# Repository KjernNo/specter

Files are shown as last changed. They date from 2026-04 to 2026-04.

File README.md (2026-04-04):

# SPECTER

SPECTER started as a little personal project, I just wanted to see what the 2.4GHz band looked like on a cheap NRF24L01 module and a Pico W. Then I added a menu. Then settings. Then OTA updates, a screensaver, a buzzer, battery monitoring and an easter egg. At some point I looked at it and thought "this is kind of a whole OS now" and figured, why not just open source it? So here we are.

It runs completely custom MicroPython firmware, no pre-built apps or libraries beyond the ssd1306 driver. The hardware is hand soldered on a 60x80mm perfboard and fits in your hand. Honestly if you are building one yourself I would go with a bigger board. 60x80mm is extremely compact and I had to use a slimmer 803160 1800mAh LiPo specifically because my usual 104050 cells are too wide and just would not fit. A bigger perfboard gives you way more headroom to work with and makes the whole build much less of a puzzle. The 60x80mm works but it is definitely not what you would call spacious haha.

Built by [Phillip Rødseth](https://kjern.no) / Kjern.no. Open source under CERN-OHL-W-2.0.

---

## What it actually does

There are 7 screens you can navigate between using the buttons. Here is what each one does and why it is useful:

**2.4G SPECTRUM**
This is the main attraction. The NRF24L01 scans every channel in the 2.4GHz band (2402-2480MHz) and draws a live bar graph across the full 128px width of the OLED. Each bar jumps up instantly when a signal is detected and falls off smoothly. There are peak markers that float above the bars and fall much slower so you can see where the action was even after it has moved on. WiFi shows up as wide solid blocks (it occupies about 20 channels at once), Bluetooth shows up as short spikes jumping around because it hops 1600 times per second. You can even hold it up against a running microwave and watch the higher frequencies light up as one big thick bar across the display, which is pretty fun :)

**WIFI SCANNER**
Uses the Pico W built in WiFi chip to scan for nearby networks. Lists them sorted by signal strength (strongest first) with SSID, dBm and channel. Scrollable with a scrollbar on the right edge.

**BT MONITOR**
Bluetooth Low Energy devices advertise themselves on three fixed channels (37, 38, 39) before they connect to anything. This screen watches all three simultaneously and shows live bar charts of activity per channel with peak markers. Good for seeing how many BLE devices are nearby.

**HOP COUNTER**
Counts how many times BLE devices switch between advertising channels per second, and plots that as a scrolling 20 second bar graph. More hops generally means more devices. Just a fun way to see the radio environment change as people walk in and out of range.

**SIGNAL METER**
A single big horizontal bar that shows signal strength on one specific channel. Use UP/DOWN to tune the channel up or down. Point the antenna at something and watch the bar react as you move closer or further away. Feels a bit like a metal detector but for radio signals. Also useful for finding which WiFi channel is least congested.

**STATS**
7 pages of real hardware stats. All of it is read from actual hardware, nothing is hardcoded or estimated. Battery voltage and percentage, CPU frequency, chip temperature from the internal sensor, RAM usage, flash usage, NRF status register, WiFi MAC address, unique chip ID, boot count and button press count this session. UP/DOWN scrolls between pages.

**SETTINGS**
Brightness, scan speed, bar decay rate, peak decay rate, battery update interval, buzzer on/off, WiFi setup and OTA firmware updates. WiFi setup has a full on-screen keyboard you can type into using the buttons. The error log viewer is also in here under "Error Log" which shows anything that crashed and got logged to flash.

---

## Hardware

You need these parts to build one:

| Part | Notes |
|---|---|
| Raspberry Pi Pico W | the brain, has built in WiFi which we use for the wifi scanner and OTA updates |
| NRF24L01+PA+LNA | the radio module, the PA+LNA version has an external antenna and is much more sensitive than the plain version |
| SSD1306 0.96" OLED | 128x64 pixels, I2C, the most common cheap OLED module around |
| 3.7V LiPo battery | single cell only, 1800-2500mAh works well |
| TP4056 charging module | handles charging safely, do not skip this |
| 5x tactile push switches | standard 6x6mm THT buttons |
| Passive piezo buzzer | needs PWM to make sound, the code drives it at 2500Hz which is a good middle ground for most passive buzzers |
| 10µF capacitor | not strictly necessary, but if your NRF acts weird when the radio activates (init failures, corrupted reads) it is usually just a voltage dip when the radio draws a burst of current. if you see this, solder a 10µF as close to the VCC and GND pins as you can and it will fix it :) |
| 2x 100kΩ resistors | voltage divider for the battery ADC sense |

For full wiring, see **[hardware/WIRING.md](hardware/WIRING.md)**. Read that before touching anything, especially the battery section. The schematic is in **[hardware/SCHEMATICS.pdf](hardware/SCHEMATICS.pdf)** if you want a technical view but WIRING.md is much easier to follow for actually building it.

> Seriously read the battery section in WIRING.md before connecting power. The voltage divider is not optional and wiring it wrong will permanently damage the ADC pin on your Pico.

---

## Installing

### The easy way, UF2 drag and drop

This is the recommended way for a first install. You do not need MicroPython installed already, the UF2 contains everything.

1. Hold **BOOTSEL** on the Pico W while plugging it into USB
2. It shows up on your computer as a USB drive called **RPI-RP2**
3. Go to [Releases](https://github.com/KjernNo/specter/releases) and download the latest **`specter-vX.X.X.uf2`**
4. Drag the UF2 file onto the RPI-RP2 drive
5. The drive disappears and the Pico reboots, SPECTER starts up

That's it. Took maybe 30 seconds.

### If SPECTER is already installed, OTA update

Go to **Settings → Check Updates** on the device. It connects to your WiFi, checks specter.kjern.no for a newer version and installs it if one is available. WiFi needs to be set up first under **Settings → WiFi Setup** where you can pick your network and type the password using the on-screen keyboard.

### Manual install, for developers

1. Flash standard MicroPython for Pico W from [micropython.org](https://micropython.org/download/RPI_PICO_W/)
2. Download the latest **`specter-firmware-vX.X.X.zip`** from [Releases](https://github.com/KjernNo/specter/releases) and extract it
3. Copy everything to the Pico keeping the folder structure exactly as it is in the zip
4. Reset and SPECTER boots

---

## Button layout

```
[ UP  ] [ DN  ] [ SEL ] [ BCK ] [ PWR ]
  GP2     GP3     GP4     GP5     GP6
```

| Button | What it does |
|---|---|
| UP | scroll up, increase a value |
| DOWN | scroll down, decrease a value |
| SELECT | open a screen, confirm something. hold 3 seconds on the menu for a surprise :) |
| BACK | exit the current screen, go back to menu, delete a character in the keyboard |
| POWER | hold 2 seconds to shut down (shows a countdown), single press to wake back up |

All buttons are wired to GND with internal pull-downs, so press = HIGH.

---

## Folder structure

```
main.py                         boots everything, runs the menu loop
VERSION                         version number, read on boot and saved to settings
core/
  hw.py                         every hardware pin definition lives here
  boot.py                       the boot screen (SPECTER / by Kjern)
  buttons.py                    debounced button reading, beeps on every press
  nrf.py                        bare metal NRF24L01 driver, RX and carrier detect only
  battery.py                    reads LiPo voltage via 100k+100k divider on GP28
  power.py                      GP6 power button, 2s hold to shut down, lightsleep wake
  buzzer.py                     PWM piezo driver at 2500Hz
  storage.py                    reads and writes JSON files to flash
  OLED/
    screensaver.py              bouncing SPECTER logo after 30s of no button presses
  error-handling/
    logger.py                   logs errors to /data/specter_log.txt (max 30 lines)
  languages/
    lang.py                     loads strings.json and returns T("key") for any screen
    strings.json                every UI string in English and Norwegian Bokmal
screens/
  screen_spectrum.py            2.4GHz live spectrum analyzer
  screen_wifi.py                WiFi network scanner
  screen_bt.py                  BLE advertising channel monitor
  screen_hop_counter.py         BLE channel hop rate counter
  screen_signal_meter.py        single channel signal strength meter
  screen_stats.py               7 pages of system stats
  screen_settings.py            settings, WiFi setup, OTA, error log
  screen_wifi_setup.py          WiFi network picker with on-screen keyboard
  screen_ota.py                 OTA firmware updater
  screen_log.py                 error log viewer
modules/
  ssd1306.py                    SSD1306 OLED driver
hardware/
  SCHEMATICS.pdf                schematic PDF export
  SPECTER.kicad_sch             KiCad schematic source
  WIRING.md                     plain language wiring guide, start here
data/                           created automatically on first boot
  specter_data.json             boot count and battery cycles
  specter_settings.json         all user settings
  specter_log.txt               error log
```

---

## OTA updates

SPECTER has a full over the air update system. When a new version is released on GitHub, the CI/CD pipeline notifies specter.kjern.no which fetches the release info from GitHub. Devices can then check for and install updates through the settings menu.

The update downloads the firmware zip directly to flash in small chunks (never buffered in RAM) then extracts it file by file, also straight from flash. This way memory is never a bottleneck even on a Pico W with everything already loaded.

After a successful install the device saves the new version number to settings and reboots into the fresh firmware.

---

## Contributing

Pull requests are very welcome! A few things to know before diving in:

Comments should explain the *why* behind decisions, not just describe what the line does. If you are adding a new feature, explain why you made the choices you did.

All UI text goes in `core/languages/strings.json`, never hardcoded in a screen file. For the English entry just write the string normally. For Norwegian just put "xxx" as a placeholder if you don't know the translation, or if you happen to be Norwegian yourself feel free to add the proper translation, it really helps when someone eventually gets the Norwegian font working (the ssd1306 font is ASCII only right now so å, ø and æ can not be displayed, but the groundwork is all there) :)

New screens go in `screens/` and need a `run(oled)` function. Add the screen to `MENU()` in `main.py` and add the menu label key to `strings.json`.

### Commit message keywords

These control what the CI/CD pipeline does with the release version:

| Keyword in commit message | Effect |
|---|---|
| `[major]` | 1.2.3 becomes 2.0.0 |
| `[minor]` | 1.2.3 becomes 1.3.0 |
| nothing | 1.2.3 becomes 1.2.4 |
| `[NO-NEW]` | version stays the same, existing release files are replaced |

Keywords are case insensitive and can go anywhere in the commit message.

---

## License

CERN Open Hardware Licence Version 2 - Weakly Reciprocal (CERN-OHL-W-2.0).

Full text in [LICENSE](LICENSE.md), attribution requirements in [NOTICE.md](NOTICE.md).

Short version: use it, modify it, sell products based on it. Just keep the source open, credit Kjern.no, and if your product has a display it must show "SPECTER, by Kjern" or equivalent on the boot screen. The credit cannot imply that Kjern.no endorses or is affiliated with your product, it is credit only.

---

*Kjern, kjern.no*

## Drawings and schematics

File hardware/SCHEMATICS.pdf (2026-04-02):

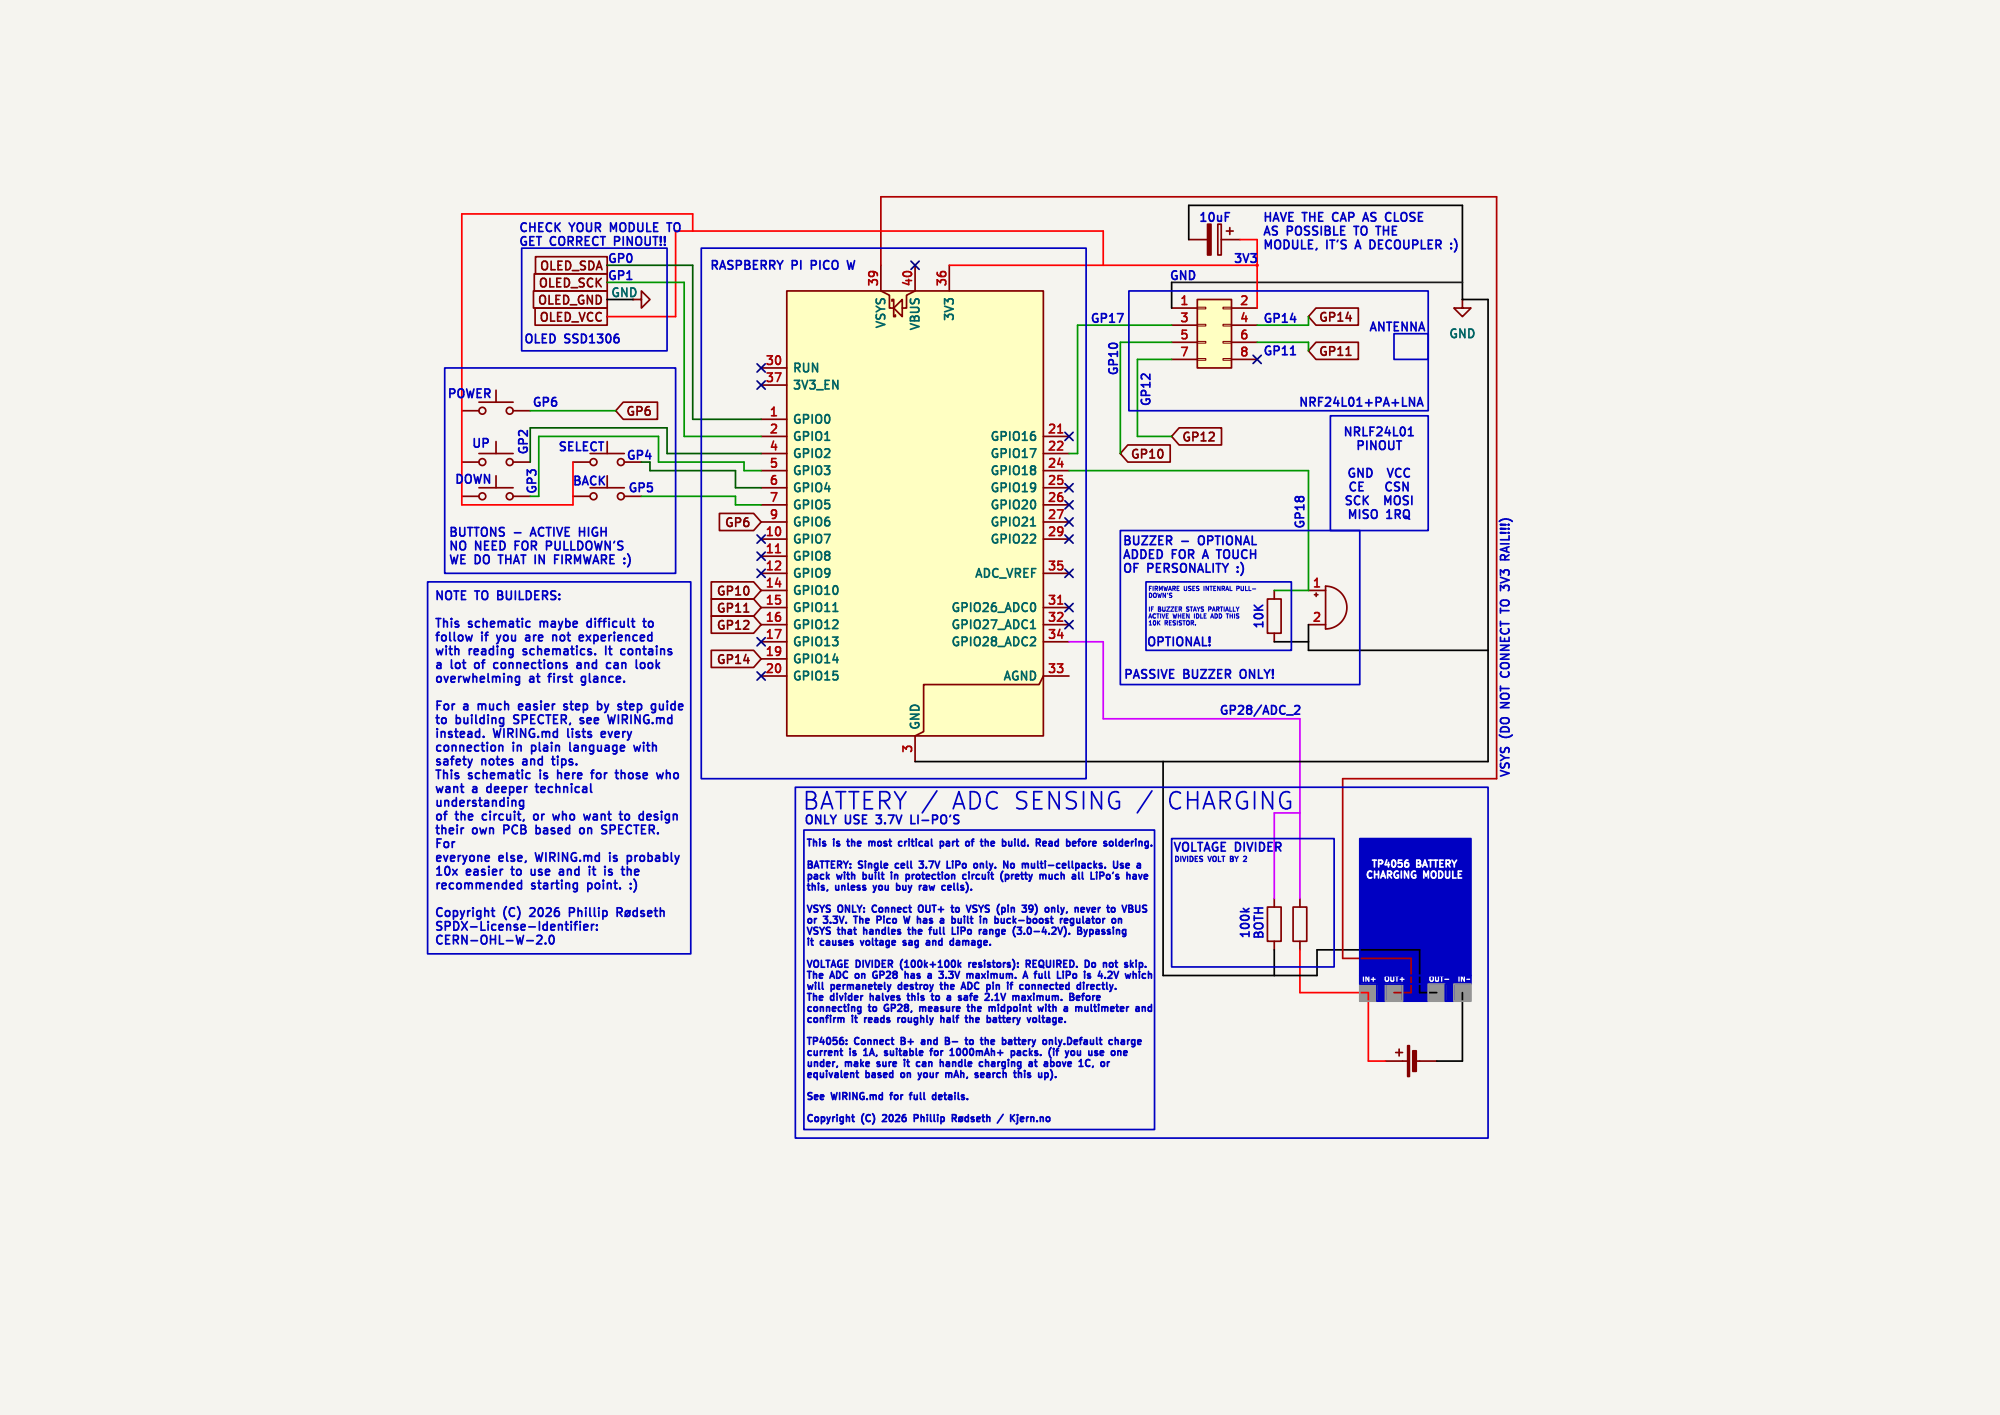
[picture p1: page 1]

10uF BUZZER - OPTIONAL ADDED FOR A TOUCH OF PERSONALITY :) 10K GP2 POWER

ANTENNA HAVE THE CAP AS CLOSE

10K RESISTOR. BUTTONS - ACTIVE HIGH

FIRMWARE USES INTENRAL PULL- DOWN'S

IF BUZZER STAYS PARTIALLY
ACTIVE WHEN IDLE ADD THIS

DIVIDES VOLT BY 2 PASSIVE BUZZER ONLY! GP28/ADC_2 100k BOTH

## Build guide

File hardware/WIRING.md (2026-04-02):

# SPECTER Wiring Guide

This is the recommended file to follow if you are building SPECTER from scratch.
The KiCad schematic (specter.kicad_sch) contains the same information but is significantly
harder to follow, especially if you are not familiar with reading schematics.
The schematic is there for people who want a deeper technical understanding of the circuit.
This file is for everyone else :)

---

## Before you start

**Read this section before connecting anything.**

### Battery safety
- Only use a **single cell 3.7V nominal LiPo battery**. Do not use 2S or higher packs.
- Connect the battery to the **VSYS pin (pin 39)** only, never to VBUS or the 3.3V rail.
  The reason is that the Pico W has a built in buck-boost regulator on VSYS that accepts
  1.8V to 5.5V and always outputs a stable 3.3V to the rest of the board. If you connect
  directly to the 3.3V rail you bypass this regulator entirely and the voltage will sag
  as the battery drains, causing unpredictable behaviour and possibly damaging the Pico.
  VSYS is designed exactly for this use case, always use it.
- Charge the battery through a **TP4056 module** only, never connect a charger directly
  to the battery or to VSYS while the Pico is running without a protection circuit.

### Voltage divider warning
The voltage divider on GP28 is extremely important and must be built correctly.
A fully charged LiPo outputs 4.2V which will damage the Pico W ADC pin if connected
directly since the ADC only handles up to 3.3V maximum.

The two 100kΩ resistors form a divider that halves the voltage:
4.2V becomes 2.1V, 3.7V becomes 1.85V, 3.0V becomes 1.5V -- all safe for the ADC.

**If you are new to voltage dividers, do the following before connecting to GP28:**
1. Build the divider on the bench with the battery connected
2. Measure the voltage at the midpoint (junction between the two resistors) with a multimeter
3. It should be roughly half the battery voltage
4. Only connect to GP28 once you have confirmed this

Getting this wrong will not cause a fire but it will permanently damage the ADC on your Pico.

---

## Wiring

### OLED Display (SSD1306, I2C)
```
OLED VCC  →  3.3V
OLED GND  →  GND
OLED SDA  →  GP0
OLED SCL  →  GP1
```

### NRF24L01+PA+LNA Radio Module
```
NRF VCC   →  3.3V
NRF GND   →  GND
NRF SCK   →  GP10
NRF MOSI  →  GP11
NRF MISO  →  GP12
NRF CSN   →  GP14
NRF CE    →  GP17
```
Add a **10µF capacitor** between NRF VCC and GND, placed as close to the module pins
as possible. The NRF draws sudden current bursts when the radio is active and without
this cap the supply voltage dips momentarily causing init failures and corrupted SPI reads.
This capacitor is not optional if you want reliable behaviour.

### Navigation Buttons (x5)
Each button has one leg on the GP pin and the other leg on 3V3.
No external resistors needed, the firmware uses internal pull-downs.
```
UP button      →  GP2  and 3V3
DOWN button    →  GP3  and 3V3
SELECT button  →  GP4  and 3V3
BACK button    →  GP5  and 3V3
POWER button   →  GP6  and 3V3
```

### Piezo Buzzer
```
Buzzer +  →  GP18
Buzzer -  →  GND
```
A 10kΩ pull-down resistor between GP18 and GND is optional. The firmware drives the pin
explicitly so it should stay silent when not active. However on some passive buzzers the
pin floating slightly can cause a faint continuous tone. If you experience this, add the
pull-down. Mark it DNP (do not populate) if you are making a PCB and only fit it if needed.

### Battery
```
Battery +  →  VSYS (Pico W pin 39)
Battery -  →  GND
```
See the battery safety note at the top of this file before connecting.

### Battery Voltage Sense (Voltage Divider)
```
Battery +  →  100kΩ  →  GP28  →  100kΩ  →  GND
```
The junction between the two resistors connects to GP28.
See the voltage divider warning at the top of this file before connecting.

### TP4056 Charging Module
```
TP4056 B+   →  Battery +
TP4056 B-   →  Battery -
```

---

## Pin summary

| GP Pin | Connected to |
|---|---|
| GP0 | OLED SDA |
| GP1 | OLED SCL |
| GP2 | Button UP |
| GP3 | Button DOWN |
| GP4 | Button SELECT |
| GP5 | Button BACK |
| GP6 | Button POWER |
| GP10 | NRF SCK |
| GP11 | NRF MOSI |
| GP12 | NRF MISO |
| GP14 | NRF CSN |
| GP17 | NRF CE |
| GP18 | Buzzer + |
| GP28 | Battery ADC (via divider) |

---

## Components list

| Component | Value / Part |
|---|---|
| Microcontroller | Raspberry Pi Pico W |
| Display | SSD1306 0.96" OLED I2C 128x64 |
| Radio module | NRF24L01+PA+LNA |
| Battery | Single cell 3.7V LiPo (1800-2500mAh recommended) |
| Charger | TP4056 module |
| Buttons | Tactile push switches x5 |
| Buzzer | Active piezo buzzer 3.3V |
| Decoupling cap (NRF) | 10µF electrolytic |
| Voltage divider R1 | 100kΩ 1/4W |
| Voltage divider R2 | 100kΩ 1/4W |
| Pull-down (buzzer) | 10kΩ 1/4W (optional, see buzzer section) |

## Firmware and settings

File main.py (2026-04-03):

# SPECTER Firmware, https://github.com/KjernNo/specter
# Copyright (C) 2026 Phillip Rødseth / Kjern.no
# SPDX-License-Identifier: CERN-OHL-W-2.0
# NOTICE: Products with a display must show "SPECTER / by Kjern" (or equivalent)
# visibly on boot. See NOTICE.md for full attribution requirements.

# main.py, the entry point for the whole OS
# this file boots everything up, sets up hardware, and runs the main menu loop
# all the actual screen logic lives in the screens/ folder
# all hardware objects are created in hw.py so everything shares the same instances
# the folder structure is:
#   core/                   hardware drivers, power, buttons, battery, lang, storage, buzzer
#   core/languages/         translation files (strings.json)
#   core/OLED/              oled related modules like the screensaver
#   core/error-handling/    error logging and crash handling
#   modules/                third party stuff like ssd1306
#   screens/                one file per screen, each has a run(oled) function
#   data/                   json files for settings and persistent data (created on first boot)

import sys

# we need to tell micropython where our folders are before importing anything
# otherwise it only looks in the root and /lib and wont find our files
sys.path.append('/core')
sys.path.append('/core/languages')
sys.path.append('/core/OLED')
sys.path.append('/core/error-handling')
sys.path.append('/modules')
sys.path.append('/screens')

import utime
from machine import Pin, reset

# boot time is captured here as early as possible, before any imports
# this is important because power.py uses it to calculate uptime accurately
# if we captured it later, the time spent importing modules would be missing
_boot_time = utime.ticks_ms()

# now we can import everything else since the paths are set up
import nrf              # nrf24l01 driver, handles all the radio stuff
import boot             # draws the boot screen with SPECTER branding
import buttons          # debounced button reading for all 4 nav buttons
import battery          # reads battery voltage from gp28 via voltage divider
import storage          # reads and writes settings and data to flash as json
import power            # handles the gp6 power button, shutdown and wake
import buzzer           # piezo buzzer feedback on gp18
import screensaver      # bouncing SPECTER logo, activates after 30s of inactivity
import logger           # error logger, writes to /data/specter_log.txt
import screen_spectrum  # 2.4ghz live spectrum analyzer with bar graph
import screen_wifi      # scans and lists nearby wifi networks
import screen_bt        # monitors ble advertising channels 37, 38, 39
import screen_stats     # shows system stats across 7 scrollable pages
import screen_settings  # lets user change settings, set up wifi, check for updates
import screen_wifi_setup # wifi network picker and on-screen keyboard for password
import screen_ota          # checks specter.kjern.no for firmware updates and installs them
import screen_hop_counter  # ble channel hop rate counter with scrolling graph
import screen_signal_meter # live signal strength meter, tunable by channel
import screen_log          # error log viewer in settings
from hw import oled     # the actual oled display object, shared across everything
from lang import T      # T("key") returns the right string for the current language

# apply the saved brightness setting right away before we draw anything
# if we dont do this here the screen might look different before and after settings load
oled.contrast(storage.get_setting('brightness'))

# -- menu -------------------------------------------------------------

def MENU():
    # the menu is a function rather than a list constant for a good reason,
    # if the user changes language in settings we want the labels to update
    # immediately when they return to the menu without needing a reboot
    # each entry is (display label, function to call when selected)
    return [
        (T("menu_spectrum"), screen_spectrum.run),
        (T("menu_wifi"),     screen_wifi.run),
        (T("menu_bt"),       screen_bt.run),
        (T("menu_hop"),      screen_hop_counter.run),
        (T("menu_signal"),   screen_signal_meter.run),
        (T("menu_stats"),    screen_stats.run),
        (T("menu_settings"), screen_settings.run),
    ]

def draw_menu(sel, batt_pct):
    # draws the main menu on the oled
    # sel is the currently highlighted item index
    # batt_pct is shown in the top right corner so you always know battery state
    oled.fill(0)

    # title on left, battery percentage on right of the header
    batt = str(batt_pct) + "%"
    oled.text(T("menu_title"), 0, 0)
    # calculate x position so the battery text is right aligned at pixel 128
    oled.text(batt, 128 - len(batt) * 8, 0)
    oled.hline(0, 9, 128, 1)   # separator line under header

    # we only show 4 items at a time because thats all that fits on 64px height
    # visible_start is the index of the first visible item
    # it scrolls down as sel goes past the 4th visible item
    menu = MENU()
    visible_start = max(0, min(sel, len(menu) - 4))
    for i, (name, _) in enumerate(menu[visible_start:visible_start + 4]):
        y      = 12 + i * 12   # each row is 12px tall
        actual = visible_start + i
        if actual == sel:
            # invert the selected row so the highlight is obvious
            oled.fill_rect(0, y - 1, 128, 11, 1)
            oled.text("> " + name, 0, y, 0)   # black text on white background
        else:
            oled.text("  " + name, 0, y, 1)   # normal white text

    oled.hline(0, 54, 128, 1)
    oled.text(T("menu_hint"), 0, 56)   # navigation hint at the bottom
    oled.show()

# -- nrf init ---------------------------------------------------------

def init_nrf():
    # tries to initialise the nrf24l01 up to 3 times
    # sometimes the module needs a moment after power on, hence the retries
    # if all 3 fail we show an error but carry on anyway
    # the spectrum and bt screens just wont work without it, but wifi and settings still will
    oled.fill(0)
    oled.text(T("menu_title"), 36, 0)
    oled.hline(0, 9, 128, 1)
    oled.text(T("nrf_init"), 20, 28)
    oled.show()

    ok = False
    for _ in range(3):
        if nrf.init():
            ok = True
            break
        utime.sleep_ms(200)   # short wait between retries

    if not ok:
        # play error sound and show diagnostics on screen
        # we show the raw status register value because its useful for debugging
        # 0x00 or 0xFF means spi is completely dead (usually a wiring issue)
        # anything else means the nrf responded but setup failed somehow
        buzzer.error()
        s = nrf.status()
        oled.fill(0)
        oled.rect(0, 0, 128, 64, 1)   # border to make the error screen look distinct
        oled.text(T("nrf_fail"),  24, 8)
        oled.hline(8, 19, 112, 1)
        oled.text("STATUS:" + hex(s), 16, 28)
        oled.text(T("nrf_check"), 12, 40)
        oled.text(T("nrf_vcc"),    4, 52)
        oled.show()
        utime.sleep_ms(2000)   # give user time to read the error before moving on

# -- easter egg -------------------------------------------------------

def _easter_egg(oled):
    # easter egg screen, triggered by holding SELECT for 3 seconds on the main menu
    # fully intentional, clearly labelled in source, not hidden or obfuscated
    # most people never read source code so it still feels like a fun discovery :)
    # if you are reading this in the source... hi! you did it the nerd way.
    # "Why not add an easter egg to this code, I mean, It is currently easter break as im developing this" - Phillip Rødseth, 3rd april 2026

    # frame 1 -- entrance, just a border pulsing in
    for i in range(4):
        oled.fill(0)
        oled.rect(i, i, 128 - i*2, 64 - i*2, 1)
        oled.show()
        utime.sleep_ms(60)

    buzzer.startup()

    # frame 2 -- main easter egg screen
    oled.fill(0)

    # double border for "..drama.."
    oled.rect(0, 0, 128, 64, 1)
    oled.rect(2, 2, 124, 60, 1)

    # big surprise header, inverted because I thought it looked better
    oled.fill_rect(4, 4, 120, 12, 1)
    oled.text("!! YOU FOUND IT !!", 4, 5, 0)   # black text on white

    # the content
    oled.text("hi from phillip :)", 4, 20)
    oled.text("kjern.no", 36, 32)

    # felt like the right call for someone who just held a button
    # for 3 seconds on a handheld RF scanner, right..?
    oled.hline(4, 46, 120, 1)
    oled.text("go touch grass", 16, 50)

    oled.show()
    utime.sleep_ms(200)

    # frame 3 -- little buzzer celebration
    buzzer.beep(30)
    utime.sleep_ms(60)
    buzzer.beep(30)
    utime.sleep_ms(60)
    buzzer.beep(60)

    utime.sleep_ms(3000)

    # frame 4 -- fade out with shrinking border
    for i in range(4):
        oled.fill(0)
        oled.rect(i, i, 128 - i*2, 64 - i*2, 1)
        oled.show()
        utime.sleep_ms(60)

    oled.fill(0)
    oled.show()

# -- main loop --------------------------------------------------------

def main():
    # this function runs the whole os, called once on boot and again on wake from power off
    # we pass a reference to this function into power.init so power.py can call main()
    # directly when the user presses gp6 to wake up, instead of doing a hardware reset
    # doing it this way keeps thonny connected and avoids the reset causing usb issues

    # capture a fresh boot time each time main() is called
    # this matters because on wake from shutdown, main() is called directly
    # by power.py and ticks_ms() has been running the whole time the pico
    # was sitting in the wake loop, so the module level _boot_time is stale
    global _boot_time
    _boot_time = utime.ticks_ms()
    power.init(oled, _boot_time, main_fn=main)

    storage.on_boot()      # increment boot counter in flash
    boot.draw_boot(oled)   # show SPECTER boot screen
    init_nrf()             # try to start the radio

    sel       = 0
    redraw    = True
    last_batt = utime.ticks_ms()
    batt_pct  = battery.percentage()   # read battery once at startup

    while True:
        # check the power button every single loop iteration
        # returns True if it was tapped briefly (cancelled), in which case we redraw
        # if it was held for 2 seconds it shuts down and never returns from check()
        if power.check(_boot_time):
            screensaver.poke()
            redraw = True

        # check if screensaver should activate after 30s of inactivity
        if screensaver.should_activate():
            screensaver.run(oled)
            redraw = True

        # battery reading is cached in battery.py so this doesnt hit the adc every loop
        # we still only update the displayed value every 30 seconds though
        # no point redrawing the menu constantly for a percentage that barely changes
        if utime.ticks_diff(utime.ticks_ms(), last_batt) > 30000:
            batt_pct  = battery.percentage()
            last_batt = utime.ticks_ms()
            redraw    = True

        if redraw:
            draw_menu(sel, batt_pct)
            redraw = False

        menu = MENU()   # call every loop so labels are always current language

        if buttons.up():
            # wrap around so going up from the first item takes you to the last
            screensaver.poke()
            sel    = (sel - 1) % len(menu)
            redraw = True

        if buttons.down():
            # wrap around so going down from the last item takes you to the first
            screensaver.poke()
            sel    = (sel + 1) % len(menu)
            redraw = True

        # select and easter egg share the same button so we read it raw
        # if released quickly = normal select, held 3 seconds = easter egg
        # this way the two actions never conflict with each other
        if buttons.btn_sel.value() == 1:
            screensaver.poke()   # any select interaction counts as activity
            utime.sleep_ms(30)   # debounce
            if buttons.btn_sel.value() == 1:
                t = utime.ticks_ms()
                while buttons.btn_sel.value() == 1:
                    if utime.ticks_diff(utime.ticks_ms(), t) >= 3000:
                        # held 3 seconds -- easter egg!
                        while buttons.btn_sel.value() == 1:
                            utime.sleep_ms(10)
                        _easter_egg(oled)
                        redraw = True
                        break
                    utime.sleep_ms(20)
                else:
                    # released before 3 seconds -- normal select action
                    screensaver.poke()
                    buzzer.double()
                    try:
                        menu[sel][1](oled)
                    except Exception as e:
                        # something crashed in a screen, log it and show error
                        # then return to menu gracefully instead of freezing
                        err = menu[sel][0] + ": " + str(e)
                        logger.log(err)
                        buzzer.error()
                        oled.fill(0)
                        oled.rect(0, 0, 128, 64, 1)
                        oled.text("SCREEN ERROR", 12, 8)
                        oled.hline(8, 19, 112, 1)
                        oled.text(str(e)[:16], 0, 24)
                        oled.text(str(e)[16:32], 0, 34)
                        oled.text("logged to file", 8, 46)
                        oled.text("returning...", 12, 56)
                        oled.show()
                        utime.sleep_ms(3000)
                    oled.contrast(storage.get_setting('brightness'))
                    redraw = True

        utime.sleep_ms(20)   # small sleep to keep cpu usage reasonable in the menu loop

main()

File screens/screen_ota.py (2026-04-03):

# SPECTER Firmware, https://github.com/KjernNo/specter
# Copyright (C) 2026 Phillip Rødseth / Kjern.no
# SPDX-License-Identifier: CERN-OHL-W-2.0
# NOTICE: Products with a display must show "SPECTER / by Kjern" (or equivalent)
# visibly on boot. See NOTICE.md for full attribution requirements.

# screen_ota.py, over the air firmware update screen
# connects to specter.kjern.no to check if a newer firmware version exists
# if one is found, asks the user if they want to install it
# downloads the update as a zip file, extracts it, replaces existing files, reboots
#
# the update server has two endpoints:
#   GET /update/version  returns json like {"version": "1.0.2"}
#   GET /update/latest   returns a 302 redirect to the github release zip
#
# urequests on pico w follows redirects automatically so the redirect is
# transparent -- we just get the zip file at the end of the chain
#
# version is read from storage so it stays correct after an ota update
# the zip extractor handles stored (method 0) and deflated (method 8) files
# wifi credentials must be saved first via the wifi setup screen

import network
import utime
import os
import gc
import storage
import buttons
import buzzer
import logger
from lang import T

# read version from settings so it reflects the actual installed version
# falls back to 1.0.0 if nothing is saved (fresh install)
def _get_current_version():
    return storage.get_setting('version') or "1.0.0"

# use http not https -- urequests on pico w can struggle with ssl on some servers
# nginx on the server handles ssl termination, the internal flask app is http
# the redirect from /update/latest goes to github which is https but
# urequests handles that redirect fine since github's ssl is standard
UPDATE_URL  = "http://specter.kjern.no/update/latest"
VERSION_URL = "http://specter.kjern.no/update/version"

def _connect_wifi(oled):
    # connect to the saved wifi network, returns wlan object if successful
    # returns None if no credentials are saved or connection times out
    ssid = storage.get_setting('wifi_ssid')
    pwd  = storage.get_setting('wifi_pass')
    if not ssid:
        return None

    oled.fill(0)
    oled.text(T("ota_title"), 36, 0)
    oled.hline(0, 9, 128, 1)
    oled.text(T("ota_connecting"), 0, 28)
    oled.show()

    wlan = network.WLAN(network.STA_IF)
    wlan.active(True)

    if wlan.isconnected():
        return wlan   # already connected, reuse it

    wlan.connect(ssid, pwd)
    t = utime.ticks_ms()
    while not wlan.isconnected():
        if utime.ticks_diff(utime.ticks_ms(), t) > 15000:
            return None
        utime.sleep_ms(300)
    return wlan

def _draw_progress(oled, label, pct):
    oled.fill(0)
    oled.text(T("ota_title"), 36, 0)
    oled.hline(0, 9, 128, 1)
    oled.text(label[:16], 0, 18)
    oled.rect(0, 32, 128, 12, 1)
    filled = int(126 * pct / 100)
    if filled > 0:
        oled.fill_rect(1, 33, filled, 10, 1)
    oled.text(str(pct) + "%", 52, 48)
    oled.show()

def _extract_zip(oled, zip_path):
    # zip extractor that reads directly from a file on flash
    # never loads more than one file at a time into RAM
    # this avoids the memory fragmentation issue of loading the whole zip at once
    #
    # reads the zip file sequentially using seek() and read()
    # for each file entry: reads header, reads compressed data, decompresses, writes
    # only the compressed data for one file is ever in RAM at a time
    import ustruct

    SIG = b'PK\x03\x04'

    # first pass: count files for progress bar
    count = 0
    with open(zip_path, 'rb') as f:
        while True:
            buf = f.read(1)
            if not buf:
                break
            if buf == b'P':
                rest = f.read(3)
                if rest == b'K\x03\x04':
                    count += 1
                else:
                    f.seek(-len(rest), 1)

    _draw_progress(oled, T("ota_installing"), 0)
    done = 0

    with open(zip_path, 'rb') as f:
        file_size = f.seek(0, 2)   # seek to end to get size
        f.seek(0)                   # back to start

        while f.tell() < file_size - 4:
            # scan for local file header signature
            buf = f.read(1)
            if not buf:
                break
            if buf != b'P':
                continue
            rest = f.read(3)
            if rest != b'K\x03\x04':
                f.seek(-len(rest), 1)
                continue

            # read local file header
            f.read(2)   # version needed
            f.read(2)   # flags
            method    = ustruct.unpack('<H', f.read(2))[0]
            f.read(4)   # mod time/date
            f.read(4)   # crc32
            comp_sz   = ustruct.unpack('<I', f.read(4))[0]
            uncomp_sz = ustruct.unpack('<I', f.read(4))[0]
            fname_len = ustruct.unpack('<H', f.read(2))[0]
            extra_len = ustruct.unpack('<H', f.read(2))[0]
            fname     = f.read(fname_len).decode('utf-8')
            f.read(extra_len)

            # read compressed data for this file only
            file_data = f.read(comp_sz)

            if fname.endswith('/'):
                try:
                    os.mkdir('/' + fname.rstrip('/'))
                except:
                    pass
                continue

            if method != 0:
                # zip was built with -0 (store only) so method should always be 0
                # if its not, skip this file rather than crashing
                logger.log("OTA: skipping file with unsupported method " + str(method) + ": " + fname)
                continue

            # create parent directories
            full_path = '/' + fname
            parts = full_path.split('/')
            for i in range(2, len(parts)):
                d = '/'.join(parts[:i])
                try:
                    os.mkdir(d)
                except:
                    pass

            with open(full_path, 'wb') as out:
                out.write(file_data)

            del file_data   # free immediately after writing
            gc.collect()

            done += 1
            _draw_progress(oled, T("ota_installing"), int(done * 100 / max(count, 1)))
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

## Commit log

2026-04-02 Update navigation button connections to 3V3
2026-04-03 fixed setting screen buzzer ON/OFF language
    Because I forgot to change it back to english after i tested how it would work with Norwegian characters haha
    [screen_settings.py]
2026-04-03 Update grep commands to be case insensitive
2026-04-03 Fix OTA to server expectations, and v1.1.0 [MINOR]
    [main.py, screen_ota.py, screen_settings.py]
2026-04-03 working OTA update system with flash streaming [minor]
    Screen OTA now streams the zip download directly to flash instead of buffering in RAM, fixing memory allocation failures on the Pico W. Zip is extracted file by file from flash so only one file is ever in RAM at a time. Workflow now builds uncompressed zips (-0) to avoid needing uzlib on the device. Version is read from storage instead of being hardcoded so the device always knows its actual installed version. Errors are logged to specter_log.txt and shown in full on the OLED.
    [screen_ota.py]
2026-04-04 Fix link to WIRING.md in release workflow
    Updated link to hardware wiring and build guide in release YAML.
2026-04-04 Clarify buzzer type and functionality in comments [patch]
    Updated comments to clarify buzzer type and usage.
    [buzzer.py]
